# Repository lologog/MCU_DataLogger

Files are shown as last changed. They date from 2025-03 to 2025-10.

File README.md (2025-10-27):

# MCU Data Logger

## Project description
In many embedded systems, there is often a lack of non-volatile or a dedicated mechanism for long-term data logging. Sensor readings, digital signals or communication data are frequently lost or must be transmitted in real time, which can be inconvenient or require constant infrastructure.

To address this limitation, I developed a compact data logger that acts as an independent module capable of storing data for later analysis. The device can capture data from digital or receive custom data frames sent by other devices via a communication bus.

## Project Goals and Scope 
- Design and build a complete embedded data-logging system including hardware, firmware and mechanical design.
- Capture data from digital inputs or communication frames transmitted over a bus.
- Store data safely in non-volatile memory (using internal CPU EEPROM or two external I<sup>2</sup>C chips).
- Provide a user interface for operation control and system status.
- Include a custom 3D-printed enclosure to protect the electronics and ensure ease of installation.

## Hardware design
The hardware is build around an ATmega328p microcontroller running with an external 16MHz crystal oscillator, ensuring stable and precise timing for all operations.
Data may be stored in two external 24LC1025 I<sup>2</sup>C EEPROM chips, which provide a large amount of non-volatile memory for long-term data logging. An additional DS1337S+ RTC module keeps accurate time for timestamping logged events.

The board includes two LEDs: one serves as a power indicator, while the second is user-programmable and can be freely controlled by the firmware for signaling various system states.
External connection are provided for 5 V power input, six digital inputs and accompanying +5 V and GND rails for convenient sensor or signal wiring. Communication and programming interfaces are also available through UART, I<sup>2</sup>C and SPI/ICSP headers.

The PCB has been designed with mechanical integration in mind.
It can be easily mounted inside the custom 3D-printed enclosure, with precisely aligned M2 mounting holes and standoff positions that provide a secure fit between the base and the upper part of the case.

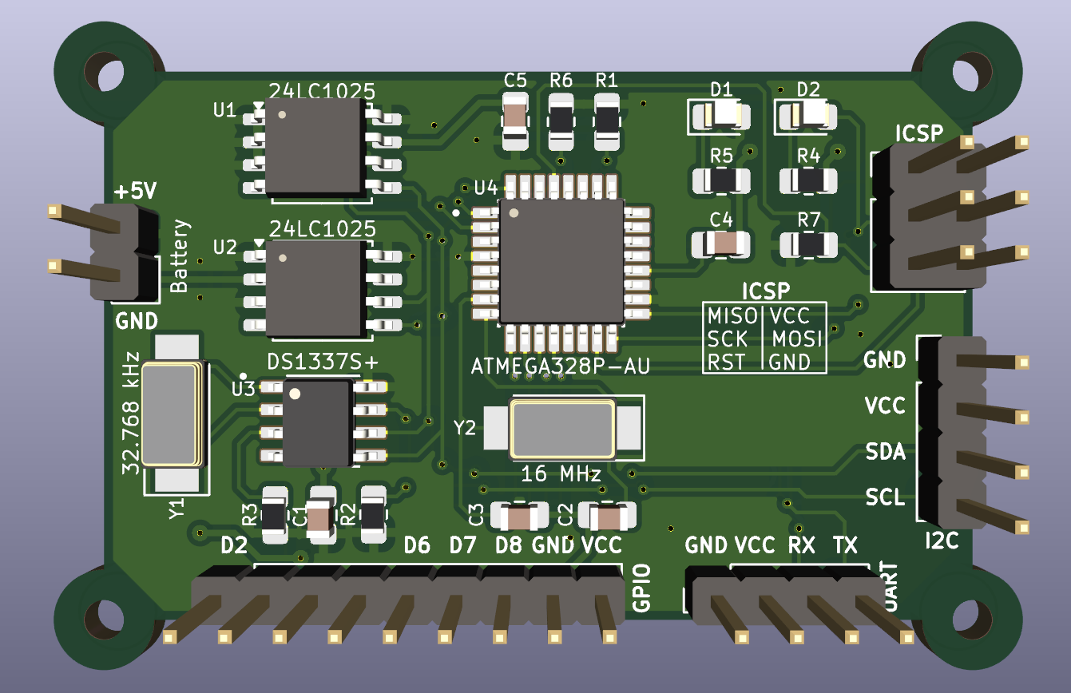
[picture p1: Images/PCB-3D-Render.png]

*3D render of the PCB board made in KiCad software*

---

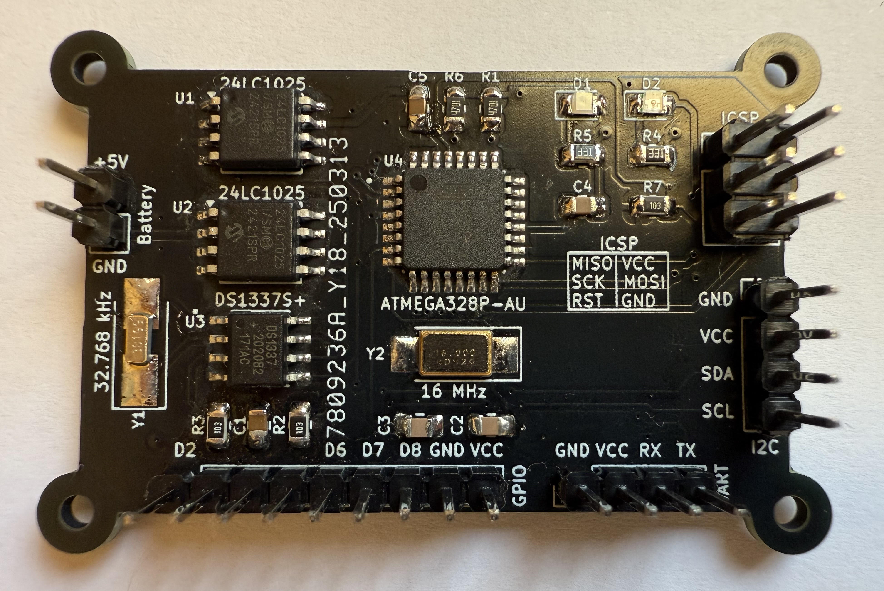
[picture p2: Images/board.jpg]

*Finished PCB board*

---

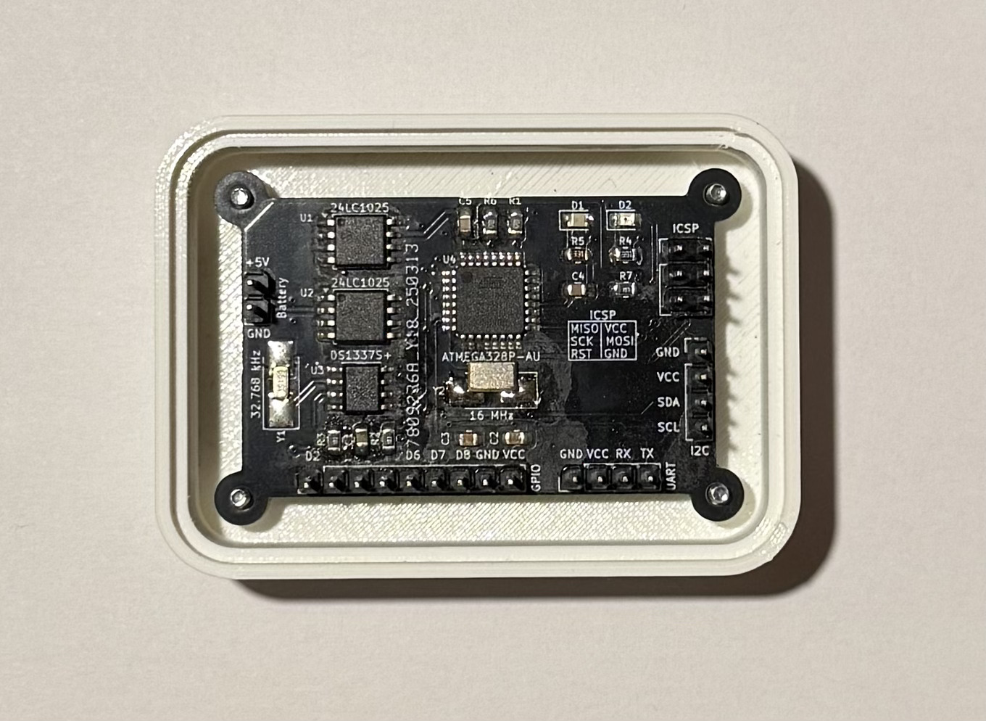
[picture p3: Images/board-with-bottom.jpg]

*PCB board with bottom part of the enclosure*

---

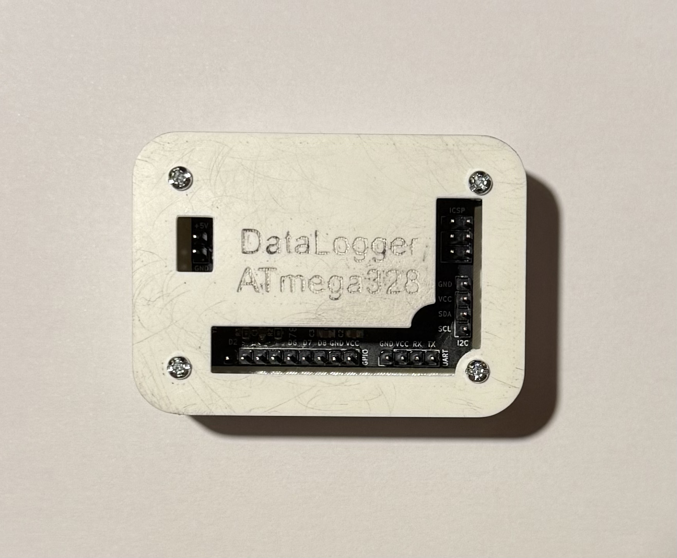
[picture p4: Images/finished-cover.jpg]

*Assembled device*

---

## Example Application - Office Window Monitor
To demonstrate the flexibility of the MCU Data Logger platform, a sample firmware project project was implemented for monitoring office windows.

The system uses six magnetic reed switches (contact sensors) connected to the digital inputs of the board. It continuously monitors each window's state, counts the number of openings and calculates the total time each window remains open.

### Communication Interface (UART)
The device communicates with a PC via UART, accepting three command codes:
- '1' - Sends the current window states , total number of openings and total open time for each channel.
- '2' - Resets all data stored in EEPROM and RAM.
- '3' - Prints the system uptime since power-on.

This allows the user to easily monitor and control the logger from a serial console or custom PC software.

### Firmware structure
The firmware was written entirely in C and designed to be modular, reusable and easy to extend for different data-logging applications. 
It is divided into two layers: a set of core low-level drivers and an application layer implementing the example project logic.

#### Core drivers
These modules provide essential hardware functionality and can be reused across multiple projects built on this platform:
- **i2c.c / i2c.h** - Communication with external 24LC1025 EEPROMs and the DS1337S+ RTC module via I<sup>2</sup>C bus
- **uart.c / uart.h** - UART serial interface for communication with a PC or other microcontrollers
- **eeprom.c / eeprom.h** - Management of non-volatile internal data storage
- **rtc.c / rtc.h** - Real-time clock driver providing precise timekeeping and timestamps

#### Application layer
This section implements the Office Window Monitor example, showcasing how the data logger can be adapted to real-world tasks:
- **windows.c / windows.h** - Detects window openings, counts events and measures how long each window remains open.
- **console.c / console.h** - handles UART command parsing and formatted data output for the serial console.

### Example UART Output
<div align="center">
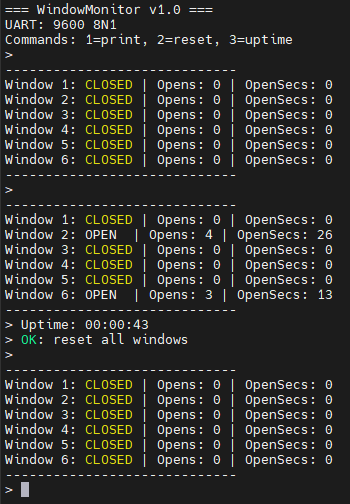
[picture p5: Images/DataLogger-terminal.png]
  
</div>

After startup, the device displays basic information such as firmware version, UART settings and available commands.
The first readout shows the initial state where all windows are closed.
After a short time, another read reveals that window 2 and 6 have been opened several times, with their total open duration displayed.
Next, the system uptime is requested and shown as 00:00:43.
Finally, the reset command is issued, clearing all stored data - the last read confirms that all counters and timers have returned to zero.

## Reusability and Development Notes
- The device operates from a 5 V power supply, which can be provided through the main power connector on the left side of the board or directly from the ICSP header during programming or testing.
- Firmware is programmed via the ICSP interface, and in this project the board was flashed using a USBasp HW-437 programmer.
- For serial communication and debugging, a USB-UART converter (FT232) was used to connect the logger to a PC terminal.

## Author
- Name: Krzysztof Tomicki
- Contact: [tomicki.krzysztof.pv@gmail.com](mailto:tomicki.krzysztof.pv@gmail.com)

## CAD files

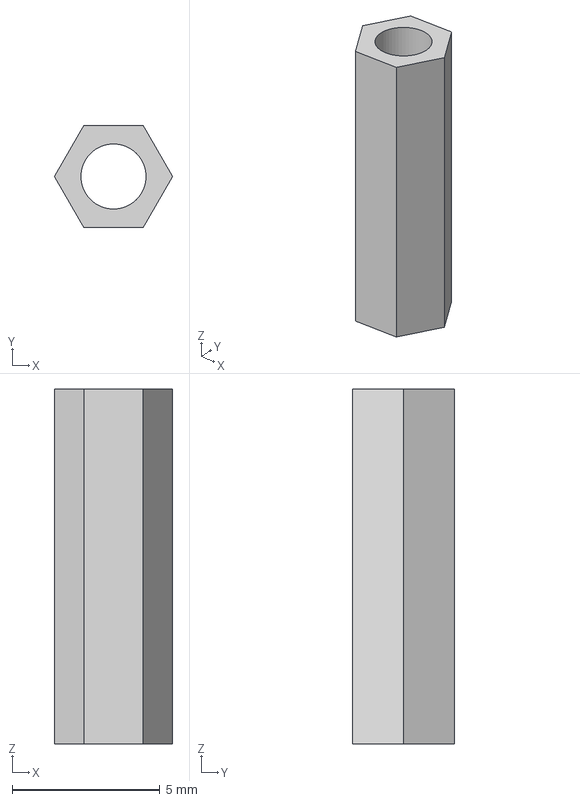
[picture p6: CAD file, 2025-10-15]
Enclosure/step/Distance_M2_12mm.step
4.00 x 3.46 x 12.0 mm

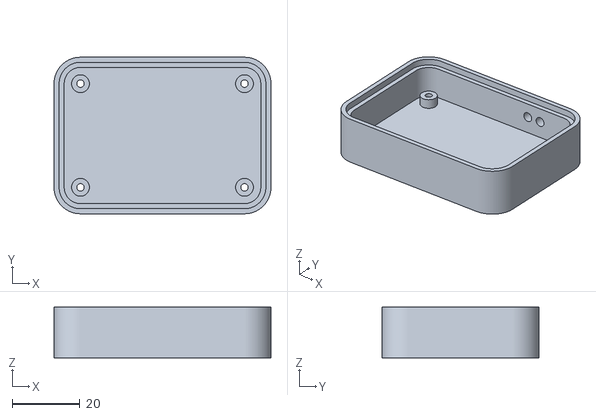
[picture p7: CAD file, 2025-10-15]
Enclosure/stl/EnclosureBottom.stl
63.8 x 46.1 x 15.0

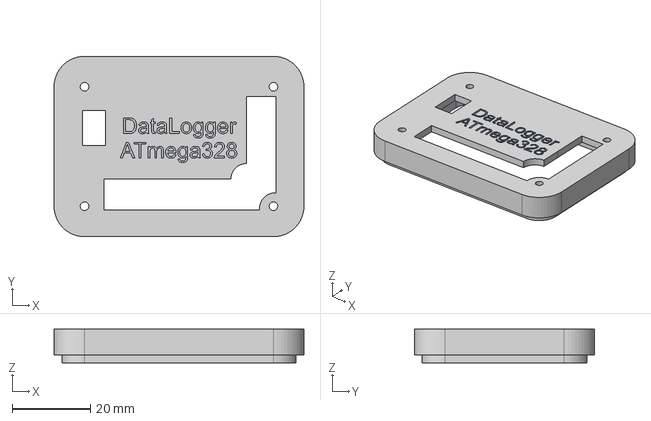
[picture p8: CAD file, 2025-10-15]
Enclosure/step/Enclosure-Top.step
63.8 x 46.1 x 8.56 mm

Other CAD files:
Enclosure/src/Distance_M2_12mm.f3d
Enclosure/src/Enclosure-Top.f3d
Enclosure/stl/Distance_M2_12mm.stl
Enclosure/stl/Enclosure-Top.stl

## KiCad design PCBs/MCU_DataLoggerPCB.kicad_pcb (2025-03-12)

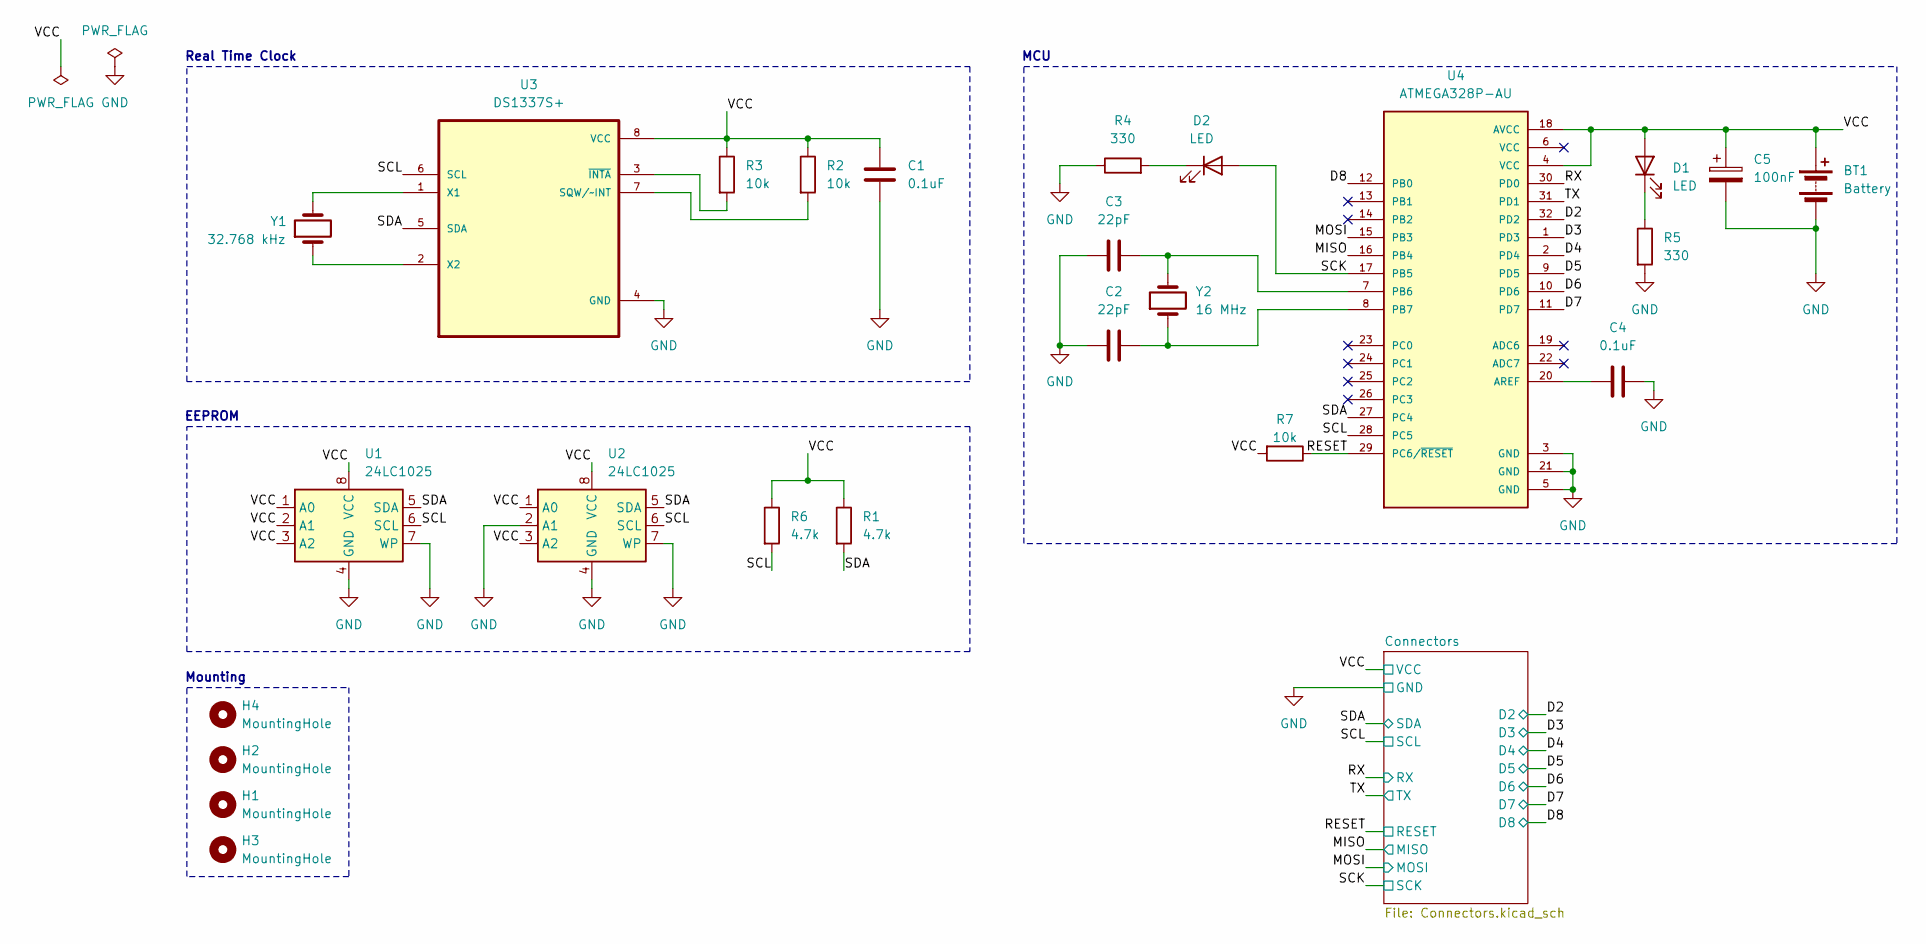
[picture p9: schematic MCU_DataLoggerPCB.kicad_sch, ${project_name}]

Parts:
BT1: Battery; PinHeader_1x02_P2.54mm_Vertical
C1, C4: 0.1uF; C_0805_2012Metric_Pad1.18x1.45mm_HandSolder
C2, C3: 22pF; C_0805_2012Metric_Pad1.18x1.45mm_HandSolder
C5: 100nF; C_0805_2012Metric_Pad1.18x1.45mm_HandSolder
D1, D2: LED; LED_0805_2012Metric_Pad1.15x1.40mm_HandSolder
H1, H2, H3, H4: MountingHole; MountingHole_2.2mm_M2
R1, R6: 4.7k; R_0805_2012Metric_Pad1.20x1.40mm_HandSolder
R2, R3, R7: 10k; R_0805_2012Metric_Pad1.20x1.40mm_HandSolder
R4, R5: 330; R_0805_2012Metric_Pad1.20x1.40mm_HandSolder
U1, U2: 24LC1025; SOIC-8_5.3x5.3mm_P1.27mm
U3: DS1337S+; SOIC127P600X175-8N
U4: ATMEGA328P-AU; QFP80P900X900X120-32N; PARTREV 8271A
Y1: 32.768 kHz; Crystal_SMD_3215-2Pin_3.2x1.5mm
Y2: 16 MHz; Crystal_SMD_5032-2Pin_5.0x3.2mm_HandSoldering

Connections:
/D2: U4.32 (PD2); also elsewhere on the board
/D3: U4.1 (PD3); also elsewhere on the board
/D4: U4.2 (PD4); also elsewhere on the board
/D5: U4.9 (PD5); also elsewhere on the board
/D6: U4.10 (PD6); also elsewhere on the board
/D7: U4.11 (PD7); also elsewhere on the board
/D8: U4.12 (PB0); also elsewhere on the board
/MISO: U4.16 (PB4); also elsewhere on the board
/MOSI: U4.15 (PB3); also elsewhere on the board
/RESET: R7.1, U4.29 (PC6/~RESET); also elsewhere on the board
/RX: U4.30 (PD0); also elsewhere on the board
/SCK: D2.2 (A), U4.17 (PB5); also elsewhere on the board
/SCL: R6.2, U1.6 (SCL), U2.6 (SCL), U3.6 (SCL), U4.28 (PC5); also elsewhere on the board
/SDA: R1.2, U1.5 (SDA), U2.5 (SDA), U3.5 (SDA), U4.27 (PC4); also elsewhere on the board
/TX: U4.31 (PD1); also elsewhere on the board
/VCC: BT1.1 (+), C1.1, C5.1, D1.2 (A), R1.1, R2.1, R3.1, R6.1, R7.2, U1.1 (A0), U1.2 (A1), U1.3 (A2), U1.8 (VCC), U2.1 (A0), U2.3 (A2), U2.8 (VCC), U3.8 (VCC), U4.4 (VCC), U4.18 (AVCC); also elsewhere on the board
GND: BT1.2 (-), C1.2, C2.1, C3.1, C4.2, C5.2, R4.1, R5.2, U1.4 (GND), U1.7 (WP), U2.2 (A1), U2.4 (GND), U2.7 (WP), U3.4 (GND), U4.3 (GND), U4.5 (GND), U4.21 (GND); also elsewhere on the board
unnamed: D1.1 (K), R5.1
unnamed: D2.1 (K), R4.2
unnamed: R2.2, U3.7 (SQW/~INT)
unnamed: U3.1 (X1), Y1.2
unnamed: U3.2 (X2), Y1.1
unnamed: R3.2, U3.3 (~INTA)
unnamed: C4.1, U4.20 (AREF)
unnamed: C3.2, U4.7 (PB6), Y2.2
unnamed: C2.2, U4.8 (PB7), Y2.1

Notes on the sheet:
Real Time Clock
EEPROM
MCU
Mounting

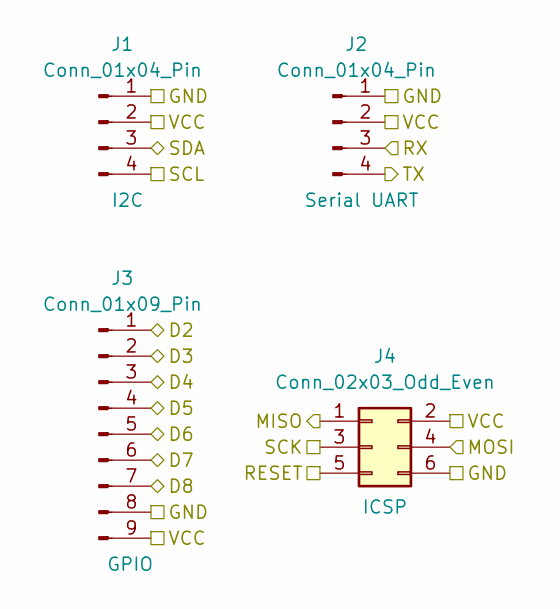
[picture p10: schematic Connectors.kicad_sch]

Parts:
J1, J2: Conn_01x04_Pin; PinHeader_1x04_P2.54mm_Vertical
J3: Conn_01x09_Pin; PinHeader_1x09_P2.54mm_Vertical
J4: Conn_02x03_Odd_Even; PinHeader_2x03_P2.54mm_Vertical

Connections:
/D2: J3.1; also elsewhere on the board
/D3: J3.2; also elsewhere on the board
/D4: J3.3; also elsewhere on the board
/D5: J3.4; also elsewhere on the board
/D6: J3.5; also elsewhere on the board
/D7: J3.6; also elsewhere on the board
/D8: J3.7; also elsewhere on the board
/MISO: J4.1; also elsewhere on the board
/MOSI: J4.4; also elsewhere on the board
/RESET: J4.5; also elsewhere on the board
/RX: J2.3; also elsewhere on the board
/SCK: J4.3; also elsewhere on the board
/SCL: J1.4; also elsewhere on the board
/SDA: J1.3; also elsewhere on the board
/TX: J2.4; also elsewhere on the board
/VCC: J1.2, J2.2, J3.9, J4.2; also elsewhere on the board
GND: J1.1, J2.1, J3.8, J4.6; also elsewhere on the board

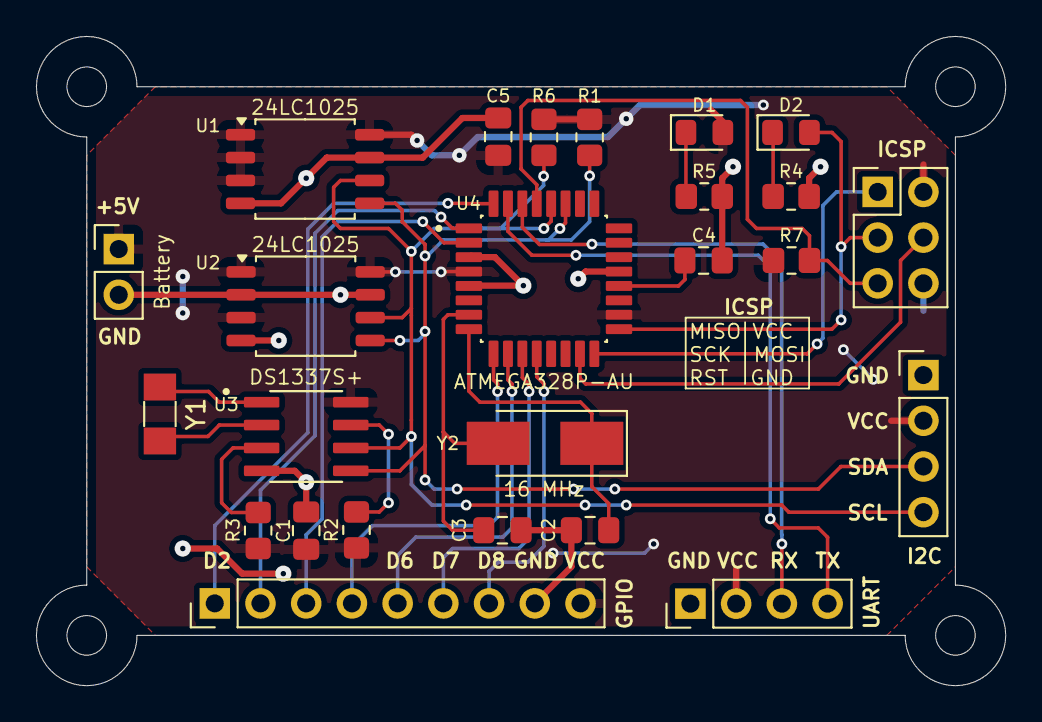
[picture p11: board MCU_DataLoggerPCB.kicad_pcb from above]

Board: 2 copper layers, 53.8 x 36.1 mm, 29 parts (0 on the bottom side), 26 nets.

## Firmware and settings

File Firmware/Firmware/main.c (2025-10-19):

/*
 * Firmware.c
 *
 * Created: 19.10.2025 14:58:19
 * Author : Krzysztof Tomicki
 * Description: Main file
 */

#define F_CPU 16000000UL

#include <avr/io.h>
#include <util/delay.h>
#include <stdio.h>
#include <string.h>
#include <avr/eeprom.h>

#include "uart.h"
#include "i2c.h"
#include "rtc.h"
#include "console.h"
#include "windows.h"
#include "config.h"
#include "eeprom.h"

const uint8_t window_pins[WINDOW_COUNT] =
{
	PD2, PD3, PD4, PD5, PD6, PD7
};

window_data_t windows[WINDOW_COUNT];
uint32_t boot_unix = 0;

int main(void) 
{
	UART_init(103); //9600 baud at 16 MHz
	I2C_init();
	init_windows();
	print_banner();
	
	boot_unix = rtc_get_unix();
	
	while (1)
	{
		uint32_t now = rtc_get_unix();
		
		update_windows(now);
		uart_console(now);
	
		_delay_ms(LOOP_MS);
	}
}

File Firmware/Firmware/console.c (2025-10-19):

/*
 * console.c
 *
 * Created: 19.10.2025 14:03:07
 * Author: Krzysztof Tomicki
 * Description: Communication with PC terminal via UART
 */ 

#include <stdio.h>

#include "console.h"
#include "config.h"
#include "rtc.h"
#include "windows.h"
#include "uart.h"

extern uint32_t boot_unix;

// Check if there is any data waiting to receive
uint8_t uart_rx_available(void)
{
	return (UCSR0A & (1 << RXC0));
}

// Read one byte from receive buffer
uint8_t uart_rx_getchar(void)
{
	return UDR0;
}

// Print project info after app start
void print_banner(void)
{
	UART_send_string("\r\n=== WindowMonitor v1.0 ===\r\n");
	UART_send_string("UART: 9600 8N1\r\n");
	UART_send_string("Commands: 1=print, 2=reset, 3=uptime\r\n");
	UART_send_string("> ");
}

// Communication logic between PC and the device
void uart_console(uint32_t now)
{
	if (uart_rx_available())
	{
		char cmd = (char)uart_rx_getchar();
		
		if (cmd == '1')
		{
			print_windows();
			UART_send_string("> ");
		}
		else if (cmd == '2')
		{
			windows_reset_data(now);
			UART_send_string("OK: reset all windows\r\n");
			UART_send_string("> ");
		}
		else if (cmd == '3')
		{
			uint32_t time = rtc_get_unix();
			uint32_t dt = (time >= boot_unix) ? (time - boot_unix) : 0;

			char buf[32];
			uint32_t hh = dt / 3600;
			uint32_t mm = (dt % 3600) / 60;
			uint32_t ss = dt % 60;
			sprintf(buf, "Uptime: %02lu:%02lu:%02lu\r\n",
			(unsigned long)hh, (unsigned long)mm, (unsigned long)ss);

			UART_send_string(buf);
			UART_send_string("> ");
		}
		else
		{
			UART_send_string("Commands: 1=print, 2=reset, 3=uptime\r\n");
			UART_send_string("> ");
		}
	}
}

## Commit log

2025-03-08 Project: Kicad project initialization
    [MCU_DataLoggerPCB.kicad_pcb, MCU_DataLoggerPCB.kicad_sch]
2025-03-10 Project: clean configured project to start the work
    [MCU_DataLoggerPCB.kicad_sch]
2025-03-10 Project: add symbols to the schematic sheets
    [Connectors.kicad_sch, MCU_DataLoggerPCB.kicad_sch]
2025-03-10 Project: change location of symbols
    [Connectors.kicad_sch, MCU_DataLoggerPCB.kicad_sch]
2025-03-10 Project: add component values
    [Connectors.kicad_sch, MCU_DataLoggerPCB.kicad_sch]
2025-03-10 Project: completed symbol-footprint associations
    [Connectors.kicad_sch, MCU_DataLoggerPCB.kicad_sch]
2025-03-10 Project: completed wiring of the main sheet
    [Connectors.kicad_sch, MCU_DataLoggerPCB.kicad_sch]
2025-03-10 Project: completed wiring the second sheet
    [Connectors.kicad_sch, MCU_DataLoggerPCB.kicad_sch]
2025-03-10 Project: Allocated GND and VCC to the Power net class
2025-03-10 Project: change location of the power flags
    [Connectors.kicad_sch, MCU_DataLoggerPCB.kicad_sch]
2025-03-10 Project: completed comments
    [Connectors.kicad_sch, MCU_DataLoggerPCB.kicad_sch]
2025-03-10 Project: Setup PCB
    [MCU_DataLoggerPCB.kicad_pcb]
2025-03-10 Project: Completed placement of the footprints
    [MCU_DataLoggerPCB.kicad_pcb]
2025-03-10 Project: add routes to the PCB
    [MCU_DataLoggerPCB.kicad_pcb]
2025-03-10 Project: small modifications in routing
    [MCU_DataLoggerPCB.kicad_pcb]
2025-03-11 Project: Completed putting silkscreen on the PCB
    [MCU_DataLoggerPCB.kicad_pcb]
2025-03-11 Project: Fix defect with SCK and SCL clocks in the schematic
    [Connectors.kicad_sch, MCU_DataLoggerPCB.kicad_sch]
2025-03-11 Project: Fixed the same error but on PCB
    [MCU_DataLoggerPCB.kicad_pcb]
2025-03-11 Project: PCB ready for manufacturing
    [MCU_DataLoggerPCB.kicad_pcb]
2025-03-11 Project: add 3D shapes
    [MCU_DataLoggerPCB.kicad_pcb]
2025-03-11 Project: Completed 2 layer PCB
    [MCU_DataLoggerPCB.kicad_pcb]
2025-03-11 Project: Added gerber directiories to gitignore
2025-03-11 Project: Added gitattributes file to ignore PCB files during merge
2025-03-11 Project: correctint file order in the repository
    [Connectors.kicad_sch, MCU_DataLoggerPCB.kicad_pcb, MCU_DataLoggerPCB.kicad_sch]
2025-03-12 Project: Added BOM and changed 32.768kHz crystal footprint to match element that was available to buy at the moment
    [MCU_DataLoggerPCB.kicad_pcb, MCU_DataLoggerPCB.kicad_sch]
2025-03-27 Project: add soldiered PCB photo
2025-03-27 README: add soldiered PCB photo
2025-03-29 PROJECT: example blink code to test if the ATMega can be programed correctly
    [main.c]
2025-03-29 PROJECT: add UART communication
2025-03-29 PROJECT: added I2C libraries and succesfully read time from RTC module
2025-03-29 PROJECT: add library to write data to EEPROM (DS1337S+) and change main to read all GPIOs state and then save it to EEPROM and print it via UART
2025-10-14 Project: Add photo of board with the cover
2025-10-15 Project: add photo of board with bottom and top
2025-10-15 Project: add enclosure folder
    [Distance_M2_12mm.f3d, Distance_M2_12mm.step, Distance_M2_12mm.stl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]
2025-10-19 Main: set pull ups on DI and switch processing logic to have software pull-downs
2025-10-19 RTC: add i2c.h include
2025-10-19 All devices tested - from now on all logging codes will be on different branches
2025-10-19 Main: set defines for loop time to avoid using raw numbers in code
    [main.c]
2025-10-19 Main: add UART control from PC
2025-10-26 [Images] rename photo of the board alone
2025-10-26 [Images] delete old board alone photo
2025-10-26 [README] add device specification description
2025-10-27 [README] fix UART output screenshot alignment in README
    Updated image display formatting in README.
